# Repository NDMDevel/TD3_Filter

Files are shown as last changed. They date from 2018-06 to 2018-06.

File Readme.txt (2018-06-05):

*************************
***** Carpeta DOCs: *****

Contiene documentacion variada, incluyendo manuales de referencia,
PCB del DAC (proyecto de Eagle) y scripts de MATLAB para diseño de
filtros y conversiones de formatos Q15.

**************************
***** Sitios utiles: *****

1- MPLAB X IDE: http://www.microchip.com/mplab/mplab-x-ide

	-> Link directo al instalador (ultima version):
	http://www.microchip.com/mplabx-ide-windows-installer
	
2- Compilador XC16: http://www.microchip.com/mplab/compilers
	
	-> Link directo al instalador de XC16 (ultima version):
	http://www.microchip.com/mplabxc16windows

3- MCC plugin: http://www.microchip.com/mplab/mplab-code-configurator

	-> Instalacion desde MPLAB X.
	
	En MPLAB X ir a: Tools->Plugins->Available Plugins. En el cuadro "Search" buscar "MCC"
	y una vez ubicado tildar el recuadro "install", luego clic en el boton "Install" (abajo a la izq.)

4- dsPIC33EP128GP502 documentacion: 
*Nota: la documentacion de modulos internos del micro (perifericos) estan abajo en la solapa "Documents", seccion "Reference Manual".

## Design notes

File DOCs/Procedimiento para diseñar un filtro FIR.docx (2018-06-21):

Procedimiento para diseñar un filtro FIR:

En el directorio del proyecto, TD3_Filter.X\DOCs\dspic_m_files, hay una serie de scripts de MATLAB que pueden usarse para diseñar el filtro.

Para el diseño de filtros FIR, pueden usarse los scripts shenoid_lp.m, shenoid_bp.m, shenoid_bs.m y shenoid_hp.m (donde lp: LowPass, bp: BandPass, bs: BandStop, hp: HighPass). Estos scripts implementan las ecuaciones 5.33 a 5.36 de la página 262 del libro de Shenoid – Introduction Digital Signal Processing and Filter Design (disponible también en el directorio DOCs). Para detalles y ejemplos de uso de estos script, desde la consola de MATLAB introducir:

>> help shenoid_xx.m Donde xx puede ser: lp, bp, bs o hp.

Debe tenerse en cuenta que todo sistema digital tiene un ancho de banda máximo impuesto por la frecuencia de muestreo sobre dos (fs/2). Es por esto que normalmente se normaliza el eje de frecuencias entre 0 y 1, donde 1 corresponde a fs/2. Por ejemplo, un filtro pasa bajos cuya frecuencia de corte normalizada es fcn = 0.25, tendrá una banda de paso que se extiende desde 0Hz hasta 0.25*fs/2. Por lo tanto la frecuencia de corte no es absoluta y depende de fs. Si fs = 1kHz, la frecuencia de corte será 125Hz; si fs = 15kHz, la frecuencia de corte será 1875Hz; etc.

Para diseñar un pasa banda entre 0.15 y 0.45 de orden 256, basta con:

>> h = shenoid_bp( 0.15 , 0.45 , 256 );

Ahora h contiene la respuesta al impulso del filtro, pero por defecto MATLAB las devuelve en tipo double, y antes de cargarlas al dspic hay que convertirlas a Q15.

Para esto se usa el script generate_q15_coefs.m que genera un archivo de texto llamado “generate_q15_coefs.txt” con las muestras en formato Q15 y formateadas adecuadamente para que sea fácil de cargar en el programa del dspic. Ejemplo:

>> generate_q15_coefs( h );

Esto genera el archivo “generate_q15_coefs.txt” que contiene lo siguiente:

h[0] = 0xffe3;

h[1] = 0xffe8;

h[2] = 0x002a;

h[3] = 0x0000;

h[4] = 0xff7f;

h[5] = 0xff61;

…

…

…

h[253] = 0x0000;

h[254] = 0x002a;

h[255] = 0xffe8;

Esto permite copiar fácilmente los 256 coeficientes del filtro en el programa del dsPIC.

Notar que en el main.c, en la función FIR_InitConfig deben cargarse estos coeficientes, y se debe modificar el #define N xxx de acuerdo a la cantidad de coeficientes.

Tambien debe modificarse la segunda línea del archivo AD1Interrupt.s para que se defina la constante Nminus1 tambien con la cantidad de coeficientes usados.

Resumen:

>> h = shenoid_bp( 0.15 , 0.45 , 256 );

>> freqz(h,1,256); % Opcional, se usa para ver la respuesta en

% frecuencia del filtro diseñado

>> generate_q15_coefs( h );

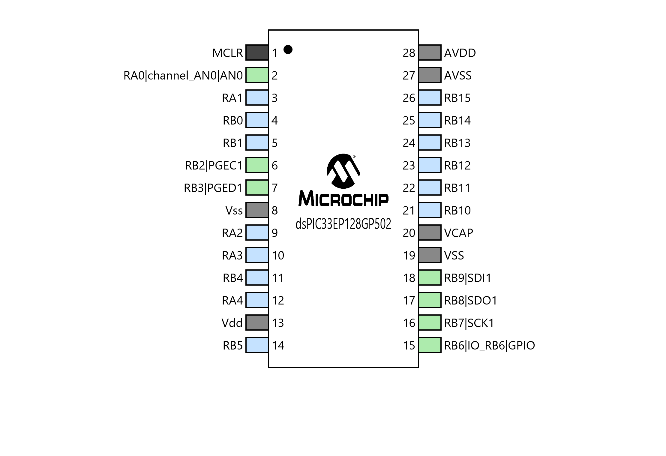
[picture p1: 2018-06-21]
DOCs/Schematic_dsPIC.png

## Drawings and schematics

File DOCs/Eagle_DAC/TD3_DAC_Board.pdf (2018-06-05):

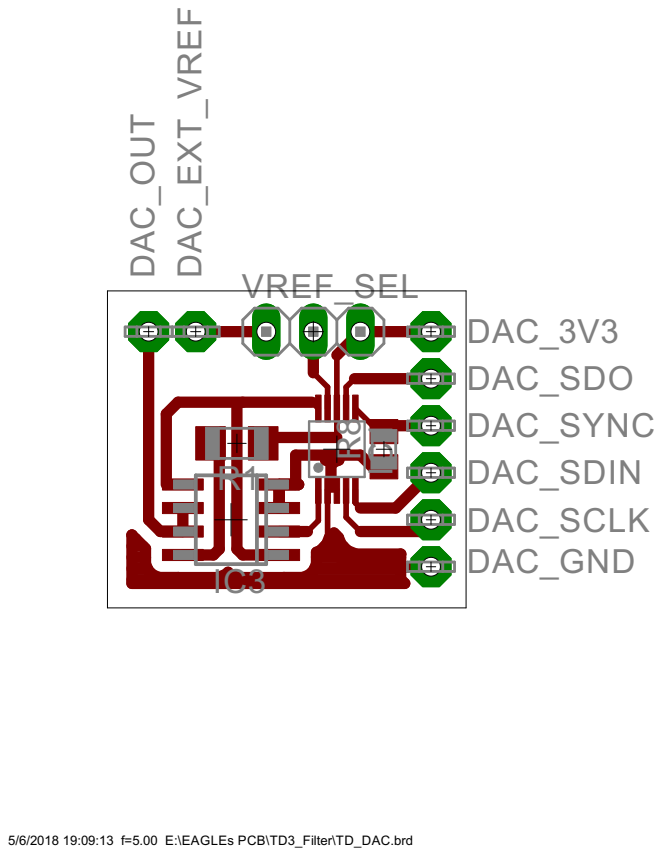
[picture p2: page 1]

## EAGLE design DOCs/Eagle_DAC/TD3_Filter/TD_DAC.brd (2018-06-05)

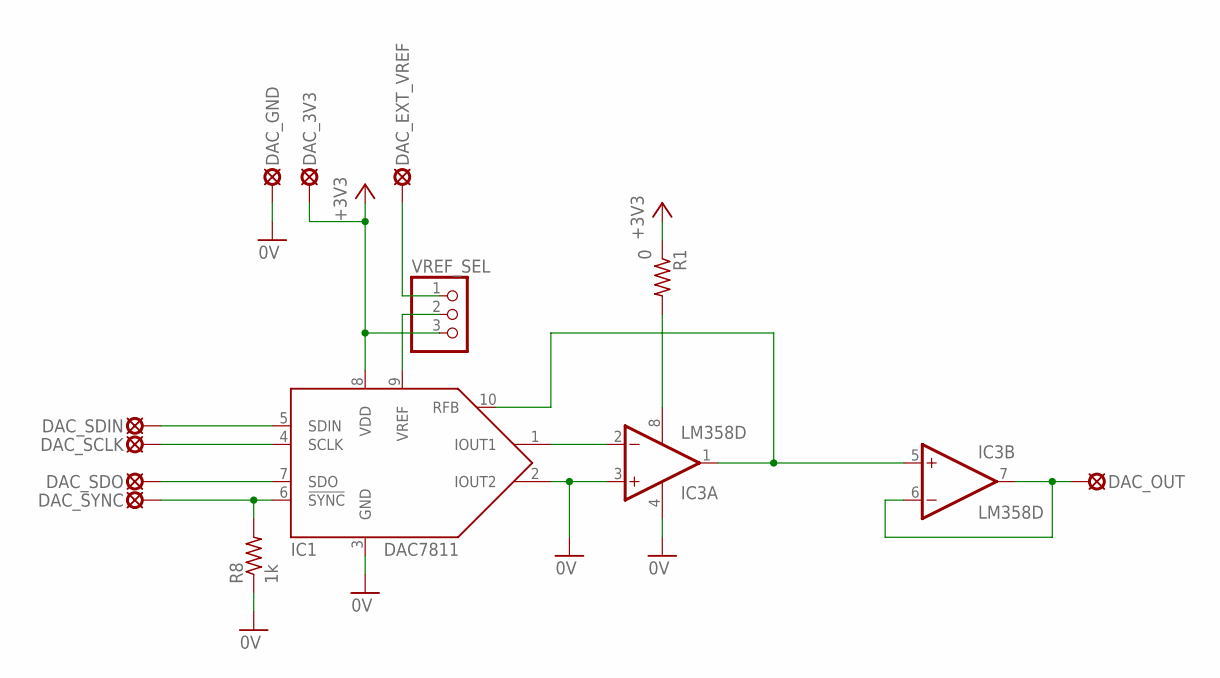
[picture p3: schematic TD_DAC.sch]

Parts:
DAC_3V3: LSP10
DAC_EXT_VREF: LSP10
DAC_GND: LSP10
DAC_OUT: LSP10
DAC_SCLK: LSP10
DAC_SDIN: LSP10
DAC_SDO: LSP10
DAC_SYNC: LSP10
IC1: DAC7811; S-PDSO-G10
IC3: LM358D; SO08
R1: 0; R1206
R8: 1k; R0805
VREF_SEL: PINHD-1X3; 1X03

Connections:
0V: DAC_GND.MP, IC1.2 (IOUT2), IC1.3 (GND), IC3.3 (+IN), IC3.4 (V-), R8.1
+3V3: DAC_3V3.MP, IC1.8 (VDD), R1.1, VREF_SEL.3
MCU_SCLK: DAC_SCLK.MP, IC1.4 (SCLK)
MCU_SDO: DAC_SDIN.MP, IC1.5 (SDIN)
unnamed: IC1.1 (IOUT1), IC3.2 (-IN)
unnamed: DAC_OUT.MP, IC3.6 (-IN), IC3.7 (OUT)
unnamed: IC1.9 (VREF), VREF_SEL.2
unnamed: DAC_EXT_VREF.MP, VREF_SEL.1
unnamed: DAC_SYNC.MP, IC1.6 (!SYNC!), R8.2
unnamed: IC1.10 (RFB), IC3.1 (OUT), IC3.5 (+IN)
unnamed: IC3.8 (V+), R1.2
unnamed: DAC_SDO.MP, IC1.7 (SDO)

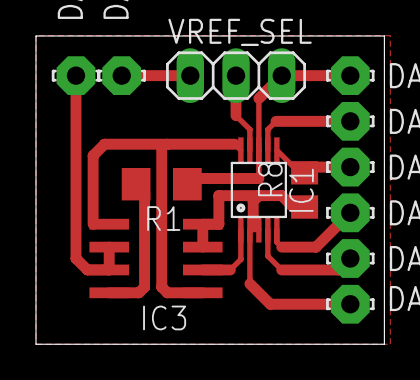
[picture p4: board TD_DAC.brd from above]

Board: 2 copper layers, 19.4 x 17.1 mm, 13 parts (0 on the bottom side), 12 nets.

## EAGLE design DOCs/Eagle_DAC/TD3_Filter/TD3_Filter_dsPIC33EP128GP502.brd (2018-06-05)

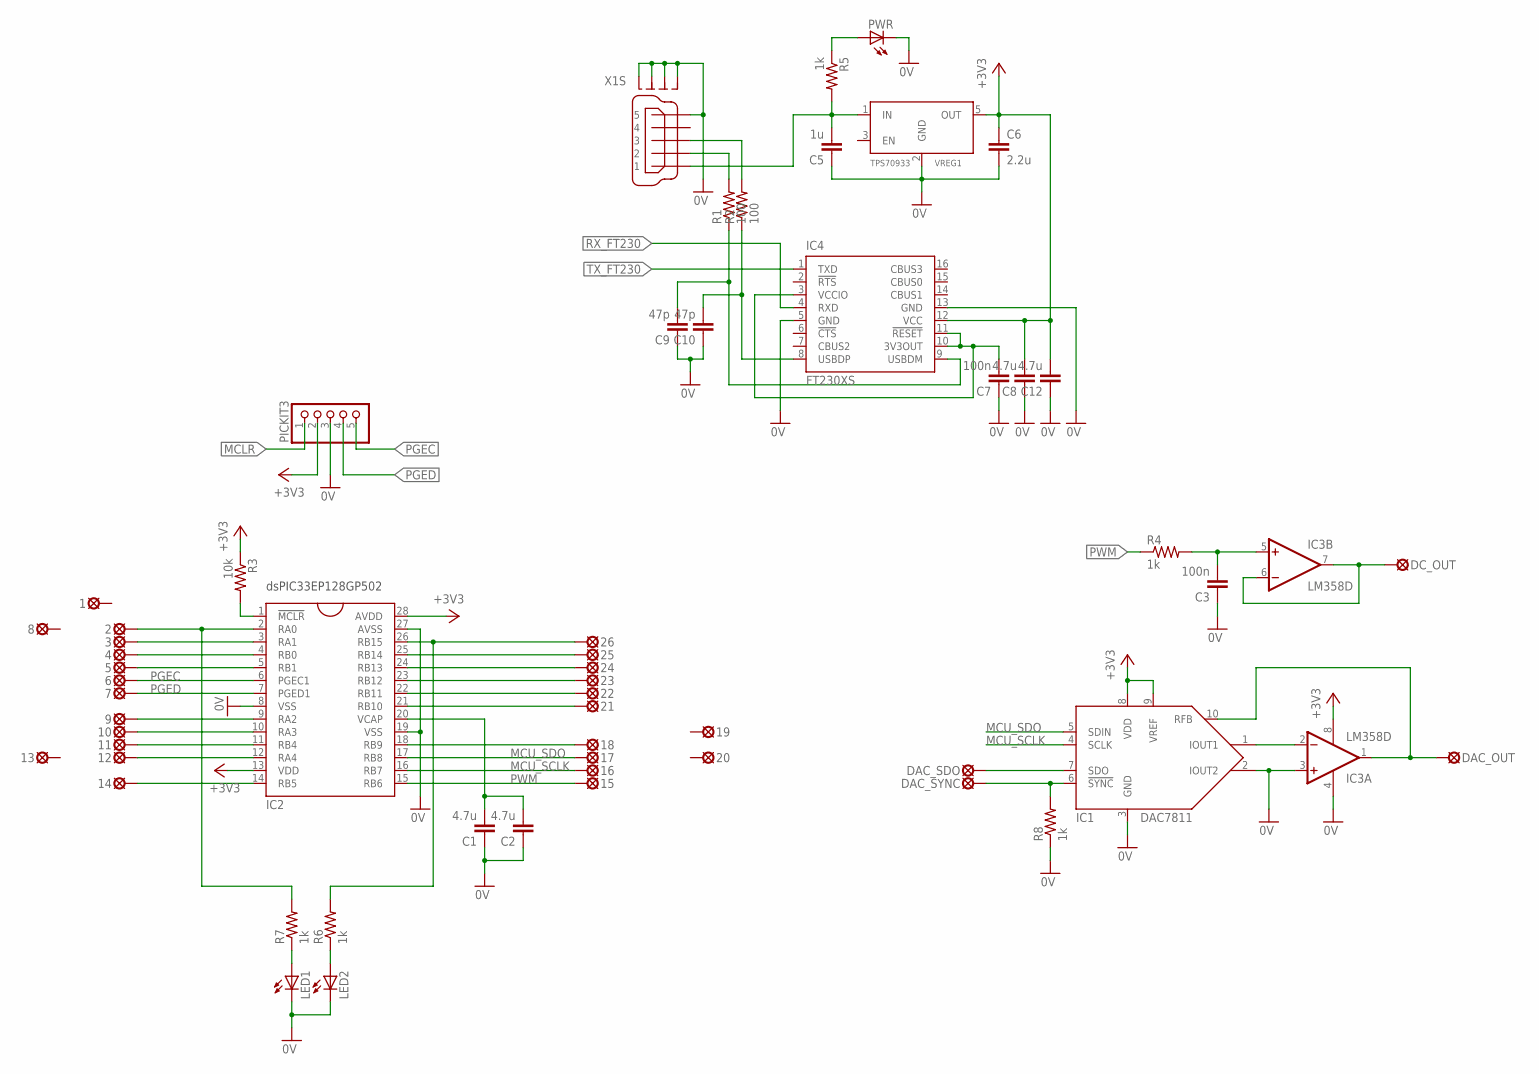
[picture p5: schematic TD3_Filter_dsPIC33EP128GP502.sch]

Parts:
1, 2, 3, 4, 5, 6, 7, 8, 9, 10, 11, 12, 13, 14, 15, 16, 17, 18, 19, 20, 21, 22, 23, 24, 25, 26: LSP10
C1, C2, C8, C12: 4.7u; C1206
C3, C7: 100n; C1206
C5: 1u; C1206
C6: 2.2u; C1206
C9, C10: 47p; C1206
DAC_OUT: LSP10
DAC_SDO: LSP10
DAC_SYNC: LSP10
DC_OUT: LSP10
IC1: DAC7811; S-PDSO-G10
IC2: DSPIC33EP128GP502; DIL28
IC3: LM358D; SO08
IC4: FT230XS; SSOP16
LED1, LED2: LED3MM
PICKIT3: PINHD-1X5; 1X05
PWR: LED3MM
R1: 100; R0805
R2: 100; R1206
R3: 10k; R0805
R4, R5, R6, R7, R8: 1k; R0805
VREG1: TPS70933
X1: MINI-USB_SHIELD5P4-32005-400; 32005-400

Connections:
0V: C1.1, C2.1, C3.1, C5.1, C6.2, C7.1, C8.1, C9.1, C10.1, C12.1, IC1.2 (IOUT2), IC1.3 (GND), IC2.8 (VSS), IC2.19 (VSS), IC2.27 (AVSS), IC3.3 (+IN), IC3.4 (V-), IC4.5 (GND), IC4.13 (GND), LED1.K (C), LED2.K (C), PICKIT3.3, PWR.K (C), R8.1, VREG1.2 (GND), X1.5, X1.M1 (S1), X1.M2 (S2), X1.M3 (S3), X1.M4 (S4)
!MCLR!: PICKIT3.1
+3V3: C6.1, C8.2, C12.2, IC1.8 (VDD), IC1.9 (VREF), IC2.13 (VDD), IC2.28 (AVDD), IC3.8 (V+), IC4.12 (VCC), PICKIT3.2, R3.1, VREG1.5 (OUT)
MCU_SCLK: 16.MP, IC1.4 (SCLK), IC2.16 (RB7)
MCU_SDO: 17.MP, IC1.5 (SDIN), IC2.17 (RB8)
unnamed: IC1.1 (IOUT1), IC3.2 (-IN)
unnamed: C3.2, IC3.5 (+IN), R4.2
unnamed: PWR.A, R5.1
unnamed: IC2.1 (!MCLR!), R3.2
unnamed: DAC_SYNC.MP, IC1.6 (!SYNC!), R8.2
unnamed: C7.2, IC4.3 (VCCIO), IC4.10 (3V3OUT), IC4.11 (!RESET)
unnamed: R2.2, X1.3
unnamed: C1.2, C2.2, IC2.20 (VCAP)
unnamed: DAC_SDO.MP, IC1.7 (SDO)
unnamed: C10.2, IC4.8 (USBDP), R2.1
unnamed: R1.2, X1.2
unnamed: C9.2, IC4.9 (USBDM), R1.1
unnamed: DAC_OUT.MP, IC1.10 (RFB), IC3.1 (OUT)
unnamed: DC_OUT.MP, IC3.6 (-IN), IC3.7 (OUT)
unnamed: 3.MP, IC2.3 (RA1)
unnamed: 4.MP, IC2.4 (RB0)
unnamed: 5.MP, IC2.5 (RB1)
unnamed: 9.MP, IC2.9 (RA2)
unnamed: 10.MP, IC2.10 (RA3)
unnamed: 11.MP, IC2.11 (RB4)
unnamed: 12.MP, IC2.12 (RA4)
unnamed: 14.MP, IC2.14 (RB5)
unnamed: 22.MP, IC2.22 (RB11)
unnamed: 18.MP, IC2.18 (RB9)
unnamed: 21.MP, IC2.21 (RB10)
unnamed: 23.MP, IC2.23 (RB12)
unnamed: 24.MP, IC2.24 (RB13)
unnamed: 25.MP, IC2.25 (RB14)
unnamed: LED2.A, R6.1
unnamed: LED1.A, R7.1
unnamed: 2.MP, IC2.2 (RA0), R7.2
unnamed: C5.2, R5.2, VREG1.1 (IN), X1.1
unnamed: 26.MP, IC2.26 (RB15), R6.2
PGEC: 6.MP, IC2.6 (PGEC1), PICKIT3.5
PGED: 7.MP, IC2.7 (PGED1), PICKIT3.4
PWM: 15.MP, IC2.15 (RB6), R4.1
RX_FT230: IC4.4 (RXD)
TX_FT230: IC4.1 (TXD)

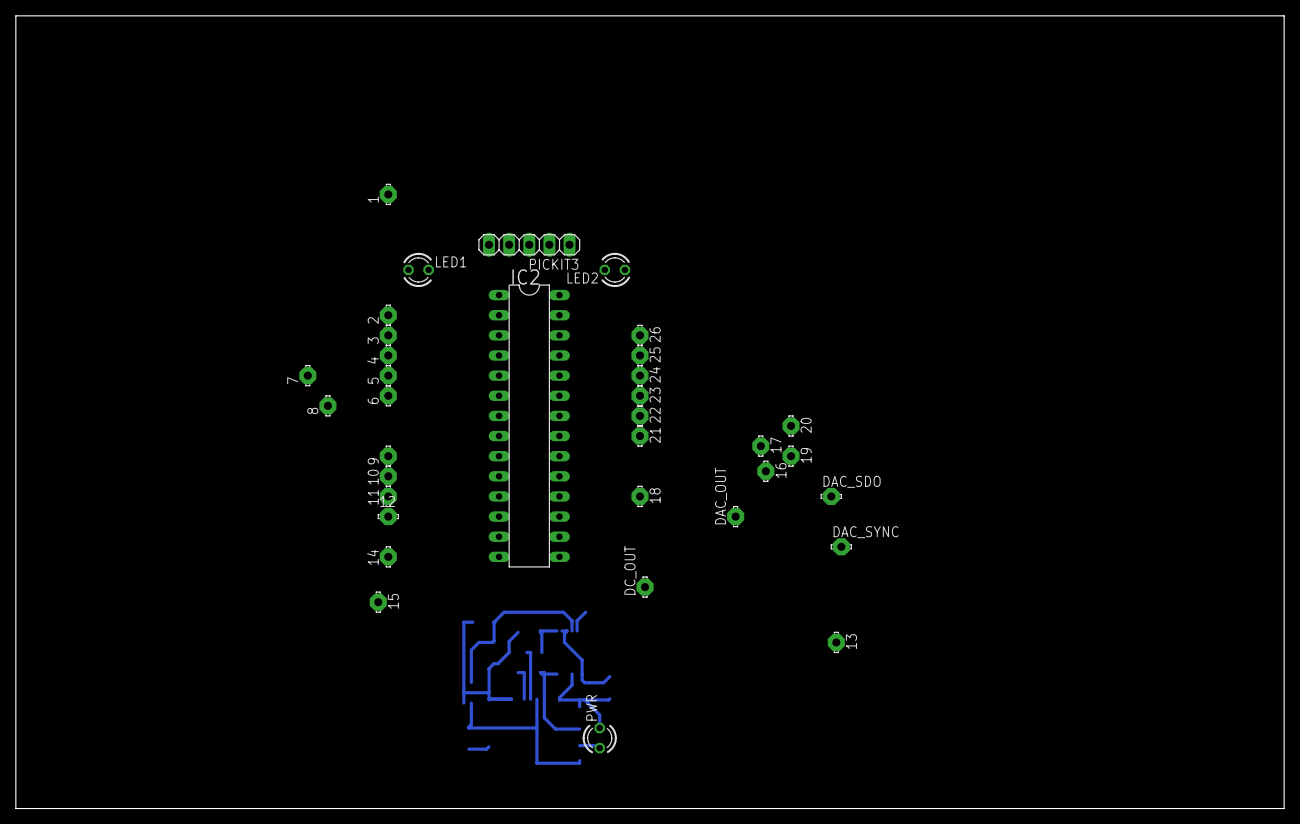
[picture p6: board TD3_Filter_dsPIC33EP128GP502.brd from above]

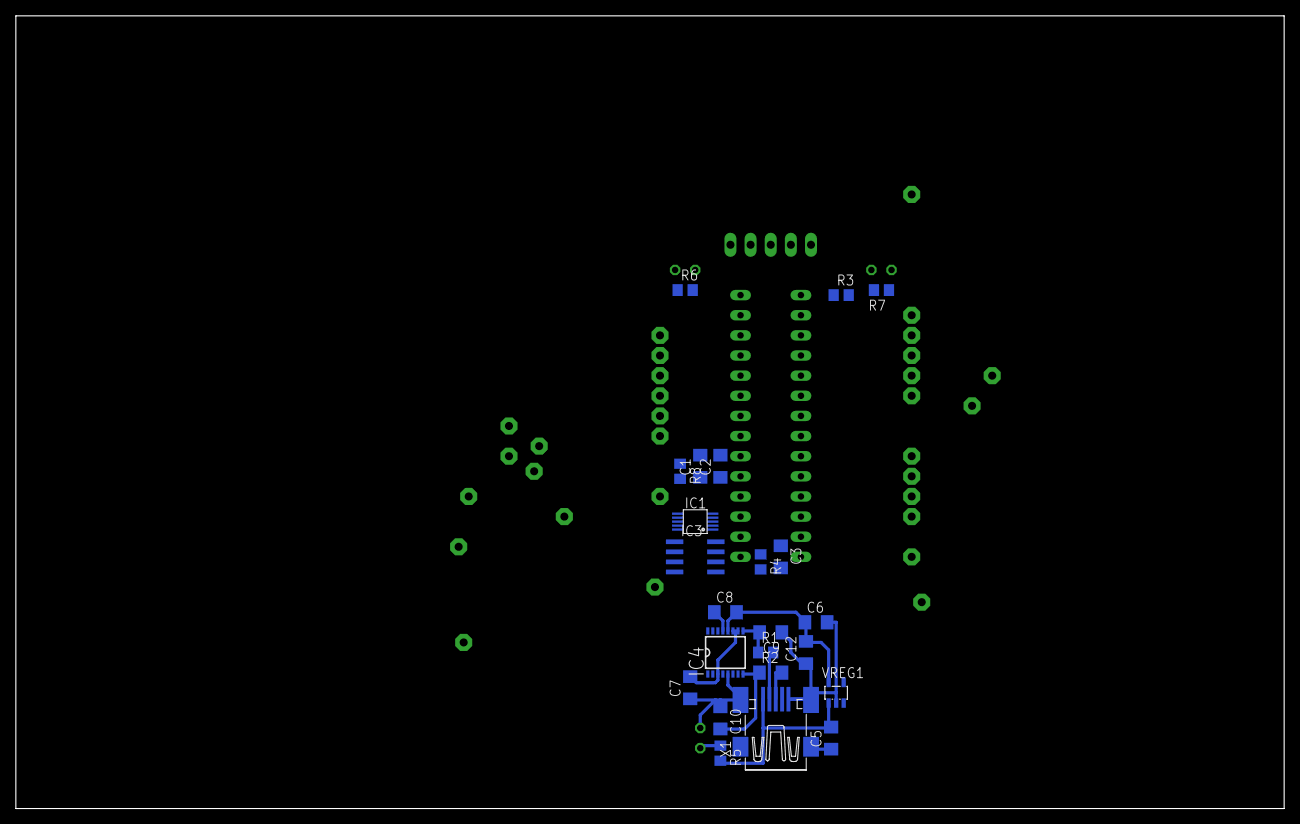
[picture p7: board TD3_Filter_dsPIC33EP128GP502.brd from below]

Board: 2 copper layers, 160.0 x 100.0 mm, 58 parts (23 on the bottom side), 40 nets.

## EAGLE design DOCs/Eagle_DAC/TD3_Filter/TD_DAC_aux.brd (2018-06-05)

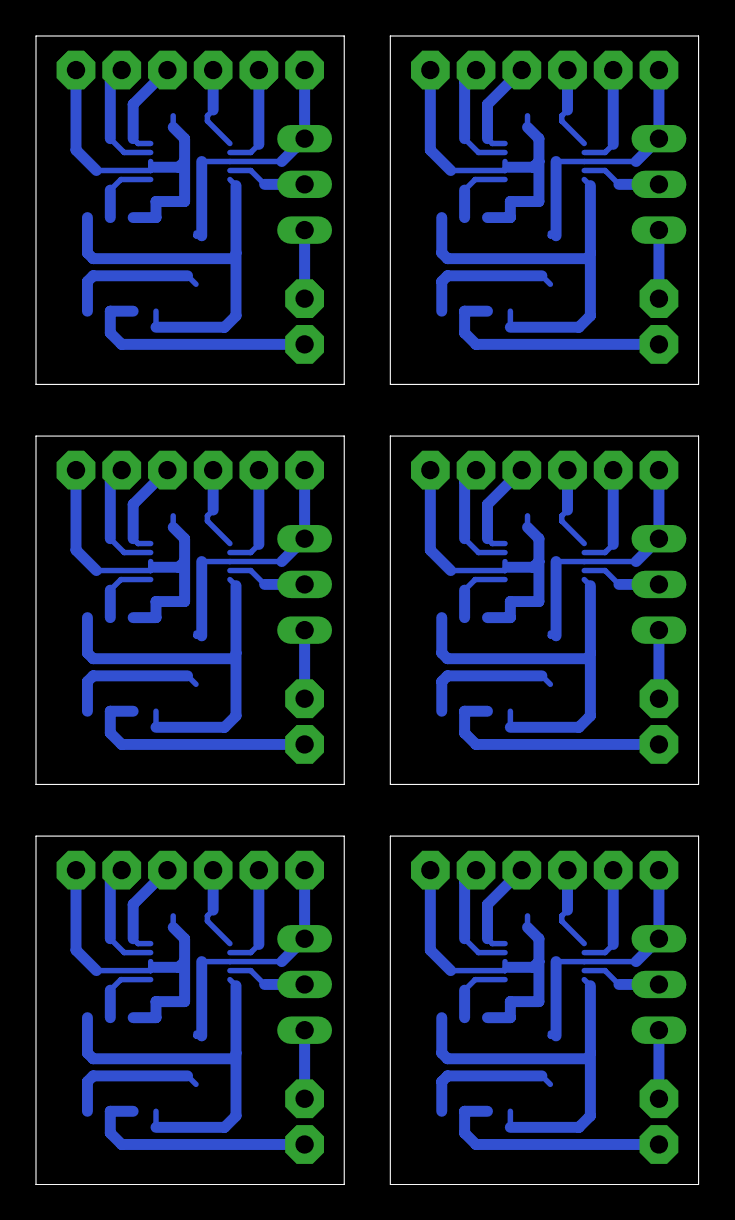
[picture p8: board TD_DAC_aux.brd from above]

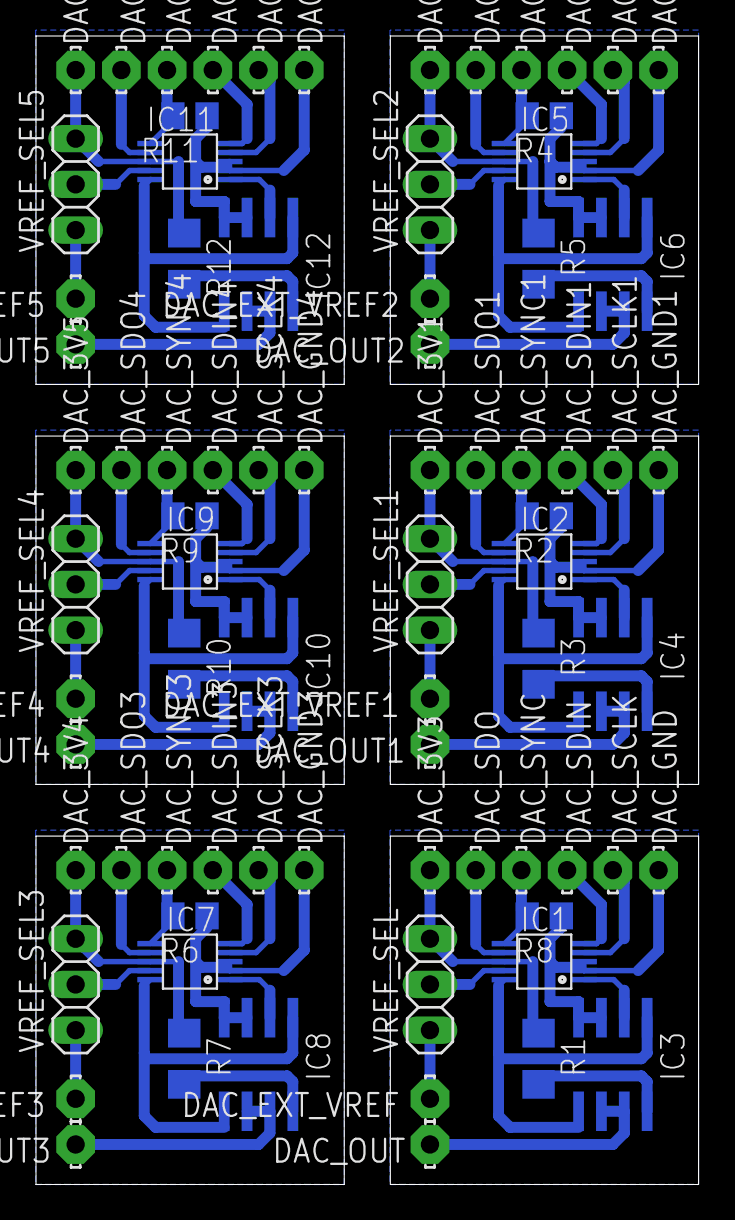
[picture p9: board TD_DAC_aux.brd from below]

Board: 2 copper layers, 36.8 x 63.8 mm, 78 parts (78 on the bottom side), 72 nets.

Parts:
DAC_3V1, DAC_3V2, DAC_3V3, DAC_3V4, DAC_3V5, DAC_3V6: LSP10
DAC_EXT_VREF, DAC_EXT_VREF1, DAC_EXT_VREF2, DAC_EXT_VREF3, DAC_EXT_VREF4, DAC_EXT_VREF5: LSP10
DAC_GND, DAC_GND1, DAC_GND2, DAC_GND3, DAC_GND4, DAC_GND5: LSP10
DAC_OUT, DAC_OUT1, DAC_OUT2, DAC_OUT3, DAC_OUT4, DAC_OUT5: LSP10
DAC_SCLK, DAC_SCLK1, DAC_SCLK2, DAC_SCLK3, DAC_SCLK4, DAC_SCLK5: LSP10
DAC_SDIN, DAC_SDIN1, DAC_SDIN2, DAC_SDIN3, DAC_SDIN4, DAC_SDIN5: LSP10
DAC_SDO, DAC_SDO1, DAC_SDO2, DAC_SDO3, DAC_SDO4, DAC_SDO5: LSP10
DAC_SYNC, DAC_SYNC1, DAC_SYNC2, DAC_SYNC3, DAC_SYNC4, DAC_SYNC5: LSP10
IC1, IC2, IC5, IC7, IC9, IC11: S-PDSO-G10
IC3, IC4, IC6, IC8, IC10, IC12: LM358D; SO08
R1, R3, R5, R7, R10, R12: 0; R1206
R2, R4, R6, R8, R9, R11: 1k; R0805
VREF_SEL, VREF_SEL1, VREF_SEL2, VREF_SEL3, VREF_SEL4, VREF_SEL5: 1X03

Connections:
0V: DAC_GND.MP, IC1.2, IC1.3, IC3.3, IC3.4, R8.1
0V1: DAC_GND1.MP, IC2.2, IC2.3, IC4.3, IC4.4, R2.1
0V2: DAC_GND2.MP, IC5.2, IC5.3, IC6.3, IC6.4, R4.1
0V3: DAC_GND3.MP, IC7.2, IC7.3, IC8.3, IC8.4, R6.1
0V4: DAC_GND4.MP, IC9.2, IC9.3, IC10.3, IC10.4, R9.1
0V5: DAC_GND5.MP, IC11.2, IC11.3, IC12.3, IC12.4, R11.1
+3V1: DAC_3V1.MP, IC2.8, R3.1, VREF_SEL1.3
+3V2: DAC_3V2.MP, IC5.8, R5.1, VREF_SEL2.3
+3V3: DAC_3V3.MP, IC1.8, R1.1, VREF_SEL.3
+3V4: DAC_3V4.MP, IC7.8, R7.1, VREF_SEL3.3
+3V5: DAC_3V5.MP, IC9.8, R10.1, VREF_SEL4.3
+3V6: DAC_3V6.MP, IC11.8, R12.1, VREF_SEL5.3
MCU_SCLK: DAC_SCLK.MP, IC1.4
MCU_SCLK1: DAC_SCLK1.MP, IC2.4
MCU_SCLK2: DAC_SCLK2.MP, IC5.4
MCU_SCLK3: DAC_SCLK3.MP, IC7.4
MCU_SCLK4: DAC_SCLK4.MP, IC9.4
MCU_SCLK5: DAC_SCLK5.MP, IC11.4
MCU_SDO: DAC_SDIN.MP, IC1.5
MCU_SDO1: DAC_SDIN1.MP, IC2.5
MCU_SDO2: DAC_SDIN2.MP, IC5.5
MCU_SDO3: DAC_SDIN3.MP, IC7.5
MCU_SDO4: DAC_SDIN4.MP, IC9.5
MCU_SDO5: DAC_SDIN5.MP, IC11.5
unnamed: IC1.1, IC3.2
unnamed: DAC_OUT.MP, IC3.6, IC3.7
unnamed: IC1.9, VREF_SEL.2
unnamed: DAC_EXT_VREF.MP, VREF_SEL.1
unnamed: DAC_SYNC.MP, IC1.6, R8.2
unnamed: IC1.10, IC3.1, IC3.5
unnamed: IC3.8, R1.2
unnamed: IC2.1, IC4.2
unnamed: DAC_SDO.MP, IC1.7
unnamed: DAC_SYNC1.MP, IC2.6, R2.2
unnamed: DAC_SDO1.MP, IC2.7
unnamed: DAC_OUT1.MP, IC4.6, IC4.7
unnamed: IC2.9, VREF_SEL1.2
unnamed: DAC_EXT_VREF1.MP, VREF_SEL1.1
unnamed: IC2.10, IC4.1, IC4.5
unnamed: IC4.8, R3.2
unnamed: IC5.1, IC6.2
unnamed: DAC_SYNC2.MP, IC5.6, R4.2
unnamed: DAC_SDO2.MP, IC5.7
unnamed: DAC_OUT2.MP, IC6.6, IC6.7
unnamed: IC5.9, VREF_SEL2.2
unnamed: DAC_EXT_VREF2.MP, VREF_SEL2.1
unnamed: IC5.10, IC6.1, IC6.5
unnamed: IC6.8, R5.2
unnamed: IC7.1, IC8.2
unnamed: DAC_SYNC3.MP, IC7.6, R6.2
unnamed: DAC_SDO3.MP, IC7.7
unnamed: DAC_OUT3.MP, IC8.6, IC8.7
unnamed: IC7.9, VREF_SEL3.2
unnamed: DAC_EXT_VREF3.MP, VREF_SEL3.1
unnamed: IC7.10, IC8.1, IC8.5
unnamed: IC8.8, R7.2
unnamed: IC9.1, IC10.2
unnamed: DAC_SYNC4.MP, IC9.6, R9.2
unnamed: DAC_SDO4.MP, IC9.7
unnamed: DAC_OUT4.MP, IC10.6, IC10.7
unnamed: IC9.9, VREF_SEL4.2
unnamed: DAC_EXT_VREF4.MP, VREF_SEL4.1
unnamed: IC9.10, IC10.1, IC10.5
unnamed: IC10.8, R10.2
unnamed: IC11.1, IC12.2
unnamed: DAC_SYNC5.MP, IC11.6, R11.2
unnamed: DAC_SDO5.MP, IC11.7
unnamed: DAC_OUT5.MP, IC12.6, IC12.7
unnamed: IC11.9, VREF_SEL5.2
unnamed: DAC_EXT_VREF5.MP, VREF_SEL5.1
unnamed: IC11.10, IC12.1, IC12.5
unnamed: IC12.8, R12.2

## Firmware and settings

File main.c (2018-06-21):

/**
  Generated Main Source File

  Company:
    Microchip Technology Inc.

  File Name:
    main.c

  Summary:
    This is the main file generated using PIC24 / dsPIC33 / PIC32MM MCUs

  Description:
    This header file provides implementations for driver APIs for all modules selected in the GUI.
    Generation Information :
        Product Revision  :  PIC24 / dsPIC33 / PIC32MM MCUs - pic24-dspic-pic32mm : 1.55
        Device            :  dsPIC33EP128GP502
    The generated drivers are tested against the following:
        Compiler          :  XC16 v1.34
        MPLAB             :  MPLAB X v4.15
*/

/*
    (c) 2016 Microchip Technology Inc. and its subsidiaries. You may use this
    software and any derivatives exclusively with Microchip products.

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
    IN NO EVENT WILL MICROCHIP BE LIABLE FOR ANY INDIRECT, SPECIAL, PUNITIVE,
    INCIDENTAL OR CONSEQUENTIAL LOSS, DAMAGE, COST OR EXPENSE OF ANY KIND
    WHATSOEVER RELATED TO THE SOFTWARE, HOWEVER CAUSED, EVEN IF MICROCHIP HAS
    BEEN ADVISED OF THE POSSIBILITY OR THE DAMAGES ARE FORESEEABLE. TO THE
    FULLEST EXTENT ALLOWED BY LAW, MICROCHIP'S TOTAL LIABILITY ON ALL CLAIMS IN
    ANY WAY RELATED TO THIS SOFTWARE WILL NOT EXCEED THE AMOUNT OF FEES, IF ANY,
    THAT YOU HAVE PAID DIRECTLY TO MICROCHIP FOR THIS SOFTWARE.

    MICROCHIP PROVIDES THIS SOFTWARE CONDITIONALLY UPON YOUR ACCEPTANCE OF THESE
    TERMS.
*/

#include "mcc_generated_files/mcc.h"
//#include "TD3_InitData.h"

#define N 128

uint16_t *posicion_inicial_del_vector_H;
uint16_t *posicion_inicial_del_vector_X;

__attribute__((space(ymemory),aligned(256))) uint16_t x[N];
__attribute__((space(xmemory),aligned(256))) uint16_t h[N]; //TD3_LOAD_MACRO;

void FIR_InitConfig(void);
void TD3_FilterConfig(void);

int main(void)
{
    SYSTEM_Initialize();    //Inicializa el micro de acuerdo a la configuracion
                            //del MCC
    
    FIR_InitConfig();       //Inicializo h[n]
    TD3_FilterConfig();     //Configuro el filtro (modulo addressing, y punteros
                            //iniciales para W8 y W10)
    
    ADC1_ChannelSelectSet(ADC1_CHANNEL_AN0);    //Seleccion del canal AN0
    ADC1_SamplingStart();                       //Inicia el muestreo
    TMR3_Start();                               //Inicia el TMR3 que al desbordar
                                                //vuelve a disparar el ADC
    
    while(1)
    {
        //Hago nada, el procesamiento DSP esta en la interrupcin por ADC.
    }
    return 0;
}

void FIR_InitConfig(void)
{
    h[0] = 0x0001;
    h[1] = 0x0011;
    h[2] = 0x0010;
    h[3] = 0xfffb;
    h[4] = 0xffe7;
    h[5] = 0xffec;
    h[6] = 0xfffe;
    h[7] = 0x0001;
    h[8] = 0xfff9;
    h[9] = 0xfffa;
    h[10] = 0x0000;
    h[11] = 0xffff;
    h[12] = 0x0007;
    h[13] = 0x000e;
    h[14] = 0xffec;
    h[15] = 0xffc9;
    h[16] = 0xffee;
    h[17] = 0xffc5;
    h[18] = 0xfe77;
    h[19] = 0xfd6b;
    h[20] = 0xffc4;
    h[21] = 0x04c6;
    h[22] = 0x05c7;
    h[23] = 0xfeaf;
    h[24] = 0xf655;
    h[25] = 0xf6df;
    h[26] = 0xfe1a;
    h[27] = 0xff72;
    h[28] = 0xf88b;
    h[29] = 0xf85f;
    h[30] = 0x0928;
    h[31] = 0x1ccb;
    h[32] = 0x1ccb;
    h[33] = 0x0928;
    h[34] = 0xf85f;
    h[35] = 0xf88b;
    h[36] = 0xff72;
    h[37] = 0xfe1a;
    h[38] = 0xf6df;
    h[39] = 0xf655;
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
}

void TD3_FilterConfig(void)
{
    posicion_inicial_del_vector_H = h;
    posicion_inicial_del_vector_X = x;

    YMODSRT = (uint16_t)x;
    YMODEND = (uint16_t)(&x[N]-1);
    MODCONbits.YWM = 10;    //W10 -> Y Space pointer
    asm("NOP");             //para que la config del buffer circular no falle
                            //la siguiente instruccion despues de setear YWM
                            //no debe ser una lectura usando punteros
    XMODSRT = (uint16_t)h;
    XMODEND = (uint16_t)(&h[N]-1);
    MODCONbits.XWM = 8;     //W8 -> X Space pointer
    asm("NOP");             //idem YWM
    
}
/**
 End of File
*/

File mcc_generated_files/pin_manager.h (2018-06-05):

/**
  System Interrupts Generated Driver File

  @Company:
    Microchip Technology Inc.

  @File Name:
    pin_manager.h

  @Summary:
    This is the generated manager file for the MPLAB(c) Code Configurator device.  This manager
    configures the pins direction, initial state, analog setting.
    The peripheral pin select, PPS, configuration is also handled by this manager.

  @Description:
    This source file provides implementations for MPLAB(c) Code Configurator interrupts.
    Generation Information :
        Product Revision  :  MPLAB(c) Code Configurator - 4.45
        Device            :  dsPIC33EP128GP502
    The generated drivers are tested against the following:
        Compiler          :  XC16 v1.34
        MPLAB             :  MPLAB X v4.15

    Copyright (c) 2013 - 2015 released Microchip Technology Inc.  All rights reserved.

    Microchip licenses to you the right to use, modify, copy and distribute
    Software only when embedded on a Microchip microcontroller or digital signal
    controller that is integrated into your product or third party product
    (pursuant to the sublicense terms in the accompanying license agreement).

    You should refer to the license agreement accompanying this Software for
    additional information regarding your rights and obligations.

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
*/

#ifndef _PIN_MANAGER_H
#define _PIN_MANAGER_H
/**
    Section: Includes
*/
#include <xc.h>
/**
    Section: Device Pin Macros
*/
/**
  @Summary
    Sets the GPIO pin, RA0, high using LATA0.

  @Description
    Sets the GPIO pin, RA0, high using LATA0.

  @Preconditions
    The RA0 must be set to an output.

  @Returns
    None.

  @Param
    None.

  @Example
    <code>
    // Set RA0 high (1)
    channel_AN0_SetHigh();
    </code>

*/
#define channel_AN0_SetHigh()          _LATA0 = 1
/**
  @Summary
    Sets the GPIO pin, RA0, low using LATA0.

  @Description
    Sets the GPIO pin, RA0, low using LATA0.

  @Preconditions
    The RA0 must be set to an output.

  @Returns
    None.

  @Param
    None.

  @Example
    <code>
    // Set RA0 low (0)
    channel_AN0_SetLow();
    </code>

*/
#define channel_AN0_SetLow()           _LATA0 = 0
/**
  @Summary
    Toggles the GPIO pin, RA0, using LATA0.

  @Description
    Toggles the GPIO pin, RA0, using LATA0.

  @Preconditions
    The RA0 must be set to an output.

  @Returns
    None.

  @Param
    None.

  @Example
    <code>
    // Toggle RA0
    channel_AN0_Toggle();
    </code>

*/
#define channel_AN0_Toggle()           _LATA0 ^= 1
/**
  @Summary
    Reads the value of the GPIO pin, RA0.

  @Description
    Reads the value of the GPIO pin, RA0.

  @Preconditions
    None.

  @Returns
    None.

  @Param
    None.

  @Example
    <code>
    uint16_t portValue;

    // Read RA0
    postValue = channel_AN0_GetValue();
    </code>

*/
#define channel_AN0_GetValue()         _RA0
/**
  @Summary
    Configures the GPIO pin, RA0, as an input.

  @Description
    Configures the GPIO pin, RA0, as an input.

  @Preconditions
    None.

  @Returns
    None.

  @Param
    None.

  @Example
    <code>
    // Sets the RA0 as an input
    channel_AN0_SetDigitalInput();
    </code>

*/
#define channel_AN0_SetDigitalInput()  _TRISA0 = 1
/**
  @Summary
    Configures the GPIO pin, RA0, as an output.

  @Description
    Configures the GPIO pin, RA0, as an output.

  @Preconditions
    None.

  @Returns
    None.

  @Param
    None.

  @Example
    <code>
    // Sets the RA0 as an output
    channel_AN0_SetDigitalOutput();
    </code>

*/
#define channel_AN0_SetDigitalOutput() _TRISA0 = 0
/**
  @Summary
    Sets the GPIO pin, RB0, high using LATB0.

  @Description
    Sets the GPIO pin, RB0, high using LATB0.

  @Preconditions
    The RB0 must be set to an output.

  @Returns
    None.

  @Param
    None.

  @Example
    <code>
    // Set RB0 high (1)
    SS1_SetHigh();
    </code>

*/
#define SS1_SetHigh()          _LATB0 = 1
/**
  @Summary
    Sets the GPIO pin, RB0, low using LATB0.

  @Description
    Sets the GPIO pin, RB0, low using LATB0.

  @Preconditions
    The RB0 must be set to an output.

  @Returns
    None.

  @Param
    None.

  @Example
    <code>
    // Set RB0 low (0)
    SS1_SetLow();
    </code>

*/
#define SS1_SetLow()           _LATB0 = 0
/**
  @Summary
    Toggles the GPIO pin, RB0, using LATB0.

  @Description
    Toggles the GPIO pin, RB0, using LATB0.

  @Preconditions
    The RB0 must be set to an output.

  @Returns
    None.

  @Param
    None.

  @Example
    <code>
    // Toggle RB0
    SS1_Toggle();
    </code>

*/
#define SS1_Toggle()           _LATB0 ^= 1
/**
  @Summary
    Reads the value of the GPIO pin, RB0.

  @Description
    Reads the value of the GPIO pin, RB0.

  @Preconditions
    None.

  @Returns
    None.

  @Param
    None.

  @Example
    <code>
    uint16_t portValue;

    // Read RB0
    postValue = SS1_GetValue();
    </code>

*/
#define SS1_GetValue()         _RB0
/**
  @Summary
    Configures the GPIO pin, RB0, as an input.

  @Description
    Configures the GPIO pin, RB0, as an input.

  @Preconditions
    None.

  @Returns
    None.

  @Param
    None.

  @Example
    <code>
    // Sets the RB0 as an input
    SS1_SetDigitalInput();
    </code>

*/
#define SS1_SetDigitalInput()  _TRISB0 = 1
/**
  @Summary
    Configures the GPIO pin, RB0, as an output.

  @Description
    Configures the GPIO pin, RB0, as an output.

  @Preconditions
    None.

  @Returns
    None.

  @Param
    None.

  @Example
    <code>
    // Sets the RB0 as an output
    SS1_SetDigitalOutput();
    </code>

*/
#define SS1_SetDigitalOutput() _TRISB0 = 0
/**
  @Summary
    Sets the GPIO pin, RB6, high using LATB6.

  @Description
    Sets the GPIO pin, RB6, high using LATB6.

  @Preconditions
    The RB6 must be set to an output.

  @Returns
    None.

  @Param
    None.

  @Example
    <code>
    // Set RB6 high (1)
    IO_RB6_SetHigh();
    </code>

*/
#define IO_RB6_SetHigh()          _LATB6 = 1
/**
  @Summary
    Sets the GPIO pin, RB6, low using LATB6.

  @Description
    Sets the GPIO pin, RB6, low using LATB6.

  @Preconditions
    The RB6 must be set to an output.

  @Returns
    None.

  @Param
    None.

  @Example
    <code>
    // Set RB6 low (0)
    IO_RB6_SetLow();
    </code>

*/
#define IO_RB6_SetLow()           _LATB6 = 0
/**
  @Summary
    Toggles the GPIO pin, RB6, using LATB6.

  @Description
    Toggles the GPIO pin, RB6, using LATB6.

  @Preconditions
    The RB6 must be set to an output.

  @Returns
    None.

  @Param
    None.

  @Example
    <code>
    // Toggle RB6
    IO_RB6_Toggle();
    </code>

*/
#define IO_RB6_Toggle()           _LATB6 ^= 1
/**
  @Summary
    Reads the value of the GPIO pin, RB6.

  @Description
    Reads the value of the GPIO pin, RB6.

  @Preconditions
    None.

  @Returns
    None.

  @Param
    None.

  @Example
    <code>
    uint16_t portValue;

    // Read RB6
    postValue = IO_RB6_GetValue();
    </code>
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

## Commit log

2018-06-05 Filtro FIR.
    TM3 es el trigger del ADC, por SPI se comunica al DAC externo.
    [MAC_Iterations.xlsx, TD3_Filter_dsPIC33EP128GP502.brd, TD3_Filter_dsPIC33EP128GP502.sch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]
2018-06-21 Filtro FIR.
    Se agrega pdf que describe como usar los script de MATLAB para diseñar FIRs y convertirlos a Q15.
